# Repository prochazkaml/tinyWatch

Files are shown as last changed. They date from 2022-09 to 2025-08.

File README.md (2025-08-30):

# tinyWatch

A simple ATtiny3224-based wristwatch with an OLED display, a couple of buttons and a CR2032 battery.

tinywatch

To build your very own tinyWatch, you'll need to source the components, get a PCB made (or make it yourself, if you're brave enough), get the plastic parts 3D printed (or, again, print it yourself if you've already got a printer) and find a compatible 18 mm watch band + push pin (or edit the .scad files if you've got some other one).

## Plastic parts

The plastic parts of the tinyWatch are expected to be 3D printed (tested FDM, but SLA should work as well). They consist of:

- the back piece where the battery and PCB will be fit
- the front piece which will hold the OLED panel as well as the buttons in place, it also contains a pair of holes at each end for fitting a watch band push pin
- OLED support piece which will make the panel not fall inside of the watch
- 3x button caps

You can find these in the [hw/3D](https://github.com/prochazkaml/tinyWatch/tree/master/hw/3D) directory in .stl format with the .scad source files are available as well.

These parts are held together with an **M3 nut and M3x6 screw**.

## PCB & Hardware

The circuit diagram as well as the PCB were designed in KiCad, the project files are available in the [hw/kicad](https://github.com/prochazkaml/tinyWatch/tree/master/hw/kicad) directory. Many prototype PCB manufacturers support uploading raw KiCad files directly without the need to generate Gerber files. Recommended PCB thickness is 1.6 mm.

Of course, you will then need to populate the manufactured PCB with components. The bill of materials is available [here](https://github.com/prochazkaml/tinyWatch/blob/master/hw/kicad/tinywatch.csv) in CSV format. In summary, you'll need:

|Component|Package|Qty|DigiKey Part Number|
|-|-|-|-|
|4.7 μF capacitor|0603|1|1276-1044-1-ND|
|1 μF capacitor|0603|5|1276-1946-1-ND|
|2.2 μF capacitor|0603|1|1276-1040-1-ND|
|10 μF capacitor|0603|1|1276-1119-1-ND|
|1N4148W diode|SOD-123|1|311-4.70KHRTR-ND|
|4-pin straight female header|4x2.54 pitch|1|S7037-ND|
|SSD1306 128x64 0.96" OLED panel|30 pin flat ribbon, 0.7 mm pitch|1|3190-DLC0096DNOG-W-5-ND (but you can probably get it much cheaper [elsewhere](https://www.aliexpress.com/item/1005006114087000.html))|
|910k resistor|0603|1|13-AC0603FR-07910KLTR-ND|
|4.7k resistor|0603|1|311-4.70KHRTR-ND|
|Push button|6.7x4.1 mm|3|CKN12330-1-ND|
|ATtiny3224|SOIC-14|1|150-ATTINY3224-SSURCT-ND|
|32.768 kHz oscillator|3.2x2.5 mm|1|50-ECS-327TXO-30-CT-ND|

What is not included in the BOM is a **CR2032** battery, with specially shaped nickel strips welded to its terminals.
The assembly instructions below go into more detail on how to prepare and connect the battery correctly.

A cheap and perfectly usable watch band is available for example from [here](https://www.aliexpress.com/item/1005002369169370.html), just remember to select the 18 mm option. I personally opted for the "ML-Black" variant, it works just fine; it even comes with the required push pins embedded into the straps themselves.

## Assembly instructions

The hardware assembly instructions are available in [a separate document](ASSEMBLY.md).

Please note that the document already assumes that you have already assembled the required components onto the tinyWatch mainboard (excluding the battery).

## Firmware building instructions

The tinyWatch's firmware is written in Rust, so you'll need the Rust toolchain to be installed.

Bulding the firmware is as easy as running the following command:

```bash
cargo build --release
```

**NOTE**: This firmware is currently only compatible with revision 2 hardware with the new ATtiny3224 microcontroller. The old revision 1 hardware is only supported by the [old C-based firmware](https://github.com/prochazkaml/tinyWatch/tree/2073f80b21bf5213d320747aeb9541f89d2ae41b).

If you have a [serialupdi](https://github.com/SpenceKonde/AVR-Guidance/blob/master/UPDI/jtag2updi.md) programmer attached to the PC as well as the watch and want to upload the firmware to the watch, run the following:

```bash
avrdude -p attiny3224 -c serialupdi -P /dev/ttyUSB0 -v -U flash:w:target/avr-none/release/tinywatch.elf
```

## Power consumption

The watch consumes roughly **4.4 mA** while the screen is on, and about **3.4 μA** while the screen is off.

If you look at your watch for a total of 5 minutes each day, that would result in about **447 μAh** of power consumption **per day**. With this usage, the 220 mAh battery in the watch should last **more than a year**.

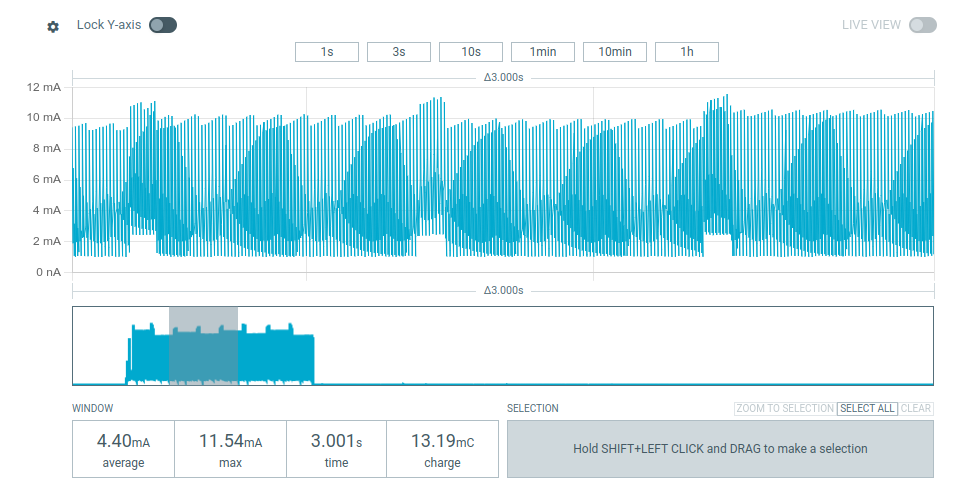
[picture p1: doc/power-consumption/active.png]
active_power_consumption


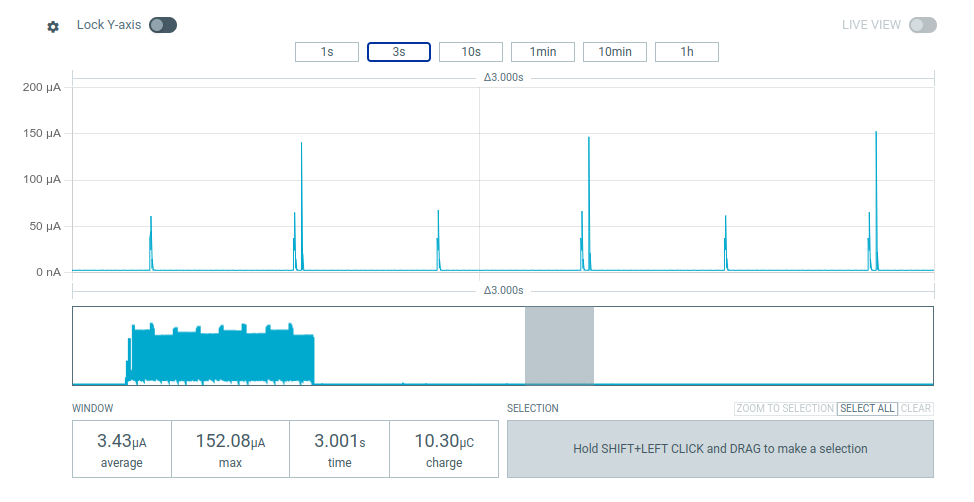
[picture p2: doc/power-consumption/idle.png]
idle_power_consumption


These measurements were taken using Nordic's [Power Profiler Kit 2](https://www.nordicsemi.com/Products/Development-hardware/Power-Profiler-Kit-2). The [raw capture file](doc/tinywatch_power_consumption.ppk2) can be viewed in the Power Profiler applet of the free and open source [nRF Connect for Desktop](https://www.nordicsemi.com/Products/Development-tools/nRF-Connect-for-Desktop) software.

## Setup

After flashing the firmware, you will want to set up the clock.
To do that, press the **left and right button** at simultaneously.
Then, using the **left** and **right** button, you will set the value on-screen and then press the **middle** button to confirm your selection and move onto the next value or finish the clock setup if you're done.
You will be asked at the end whether the entered values are correct.

## Oscillator calibration

> [!NOTE]  
> Revision 2 hardware uses a high quality temperature-compensated crystal oscillator with at most ±5 ppm of error, resulting in less than 0.5 seconds of drift per day.
> With this hardware, this option should be left alone.

If you experience severe drifts with the watch (more than 1 second per day), it is possible to trim the oscillator to a more precise value.

To remedy this issue, press the **left and middle button** together to enter the clock calibration menu.
There, you will be presented by a 16-bit hex value (the default is 8000, corresponding to the 32.768 kHz of the main oscillator).
With the **left** and **right** button, you can move the cursor.

To edit a value of a digit, press the **middle** button (the cursor will appear above the digit so that it is apparent what the buttons currently do)
and adjust the value using the **left** and **right** button.

To confirm your choice, press the **middle** button again to go back to cursor mode. Choose `Done` and press the **middle** button to exit.

## General usage

Once your watch is set up with the correct time, it is now ready to serve your everyday needs of checking the time.
Simply push any of its buttons and it will light up for a few seconds to tell you the time, before turning off again to conserve power.

---

That's it! Enjoy your watch. More features coming soon ;)

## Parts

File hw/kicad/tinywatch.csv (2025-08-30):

Reference | Value | Footprint | Qty
C1 | 4u7 | Capacitor_SMD:C_0603_1608Metric_Pad1.08x0.95mm_HandSolder | 1
C2,C3,C4,C5,C8 | 1u | Capacitor_SMD:C_0603_1608Metric_Pad1.08x0.95mm_HandSolder | 5
C6 | 2u2 | Capacitor_SMD:C_0603_1608Metric_Pad1.08x0.95mm_HandSolder | 1
C7 | 10u | Capacitor_SMD:C_0603_1608Metric_Pad1.08x0.95mm_HandSolder | 1
D1 | 1N4148W | Diode_SMD:D_SOD-123 | 1
J1 | Conn_01x04 | Connector_PinSocket_2.54mm:PinSocket_1x04_P2.54mm_Horizontal | 1
J2 | Conn_01x30 | Display:OLED-128O064D | 1
R4 | 910k | Resistor_SMD:R_0603_1608Metric_Pad0.98x0.95mm_HandSolder | 1
R5 | 4k7 | Resistor_SMD:R_0603_1608Metric_Pad0.98x0.95mm_HandSolder | 1
SW1,SW2,SW3 | SW_Push | Button_Switch_SMD:SW_DIP_SPSTx01_Slide_6.7x4.1mm_W6.73mm_P2.54mm_LowProfile_JPin | 3
U1 | ATtiny3224-SS | Package_SO:SOIC-14_3.9x8.7mm_P1.27mm | 1
Y2 | ECS-327TXO-30 | Oscillator:Oscillator_SMD_EuroQuartz_XO32-4Pin_3.2x2.5mm | 1

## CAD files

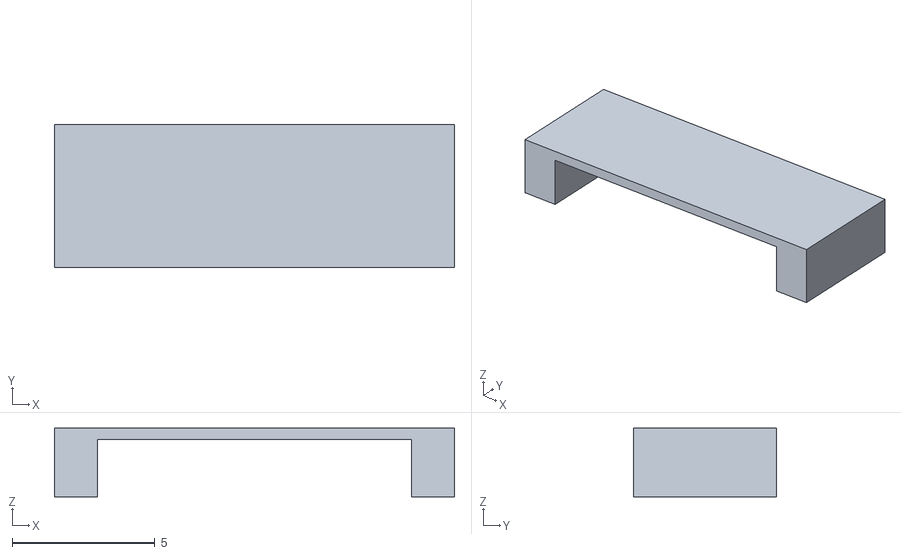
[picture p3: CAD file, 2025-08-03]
hw/3D/oledsupport.stl
14.0 x 5.00 x 2.40

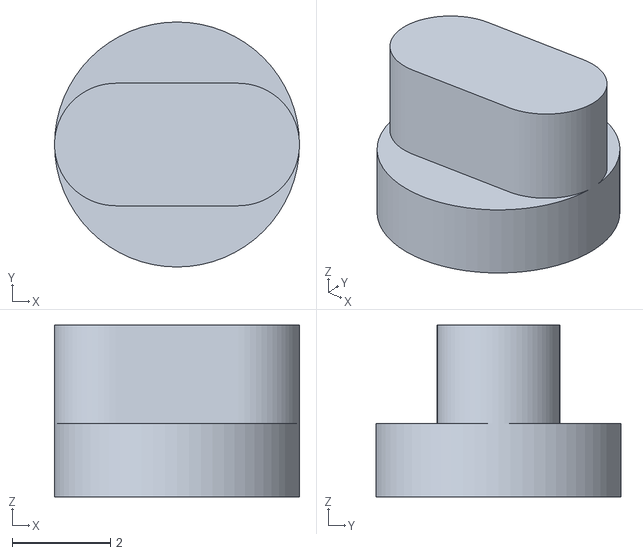
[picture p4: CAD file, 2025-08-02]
hw/3D/buttons.stl
5.00 x 5.00 x 3.50

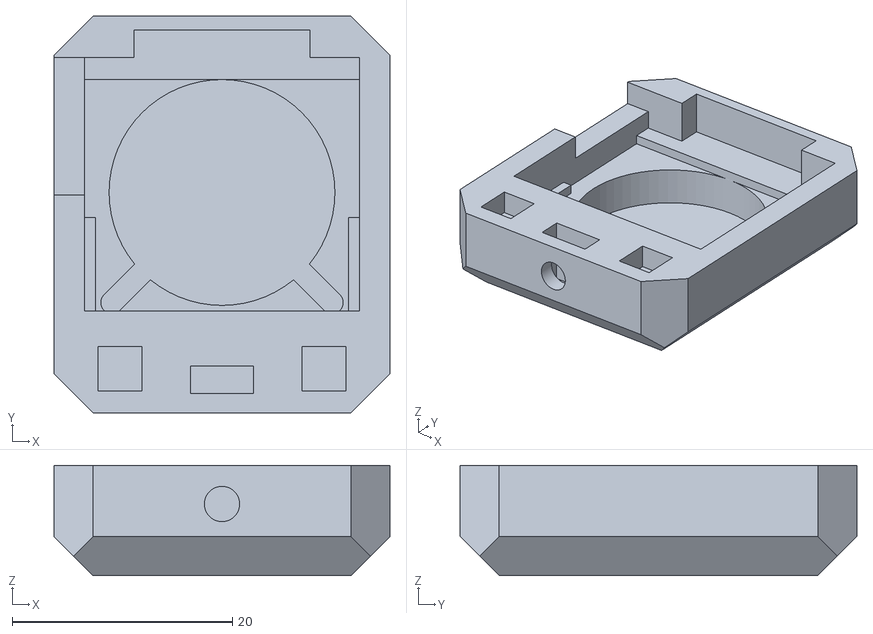
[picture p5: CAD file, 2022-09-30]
hw/3D/watch.stl
30.5 x 36.0 x 10.0

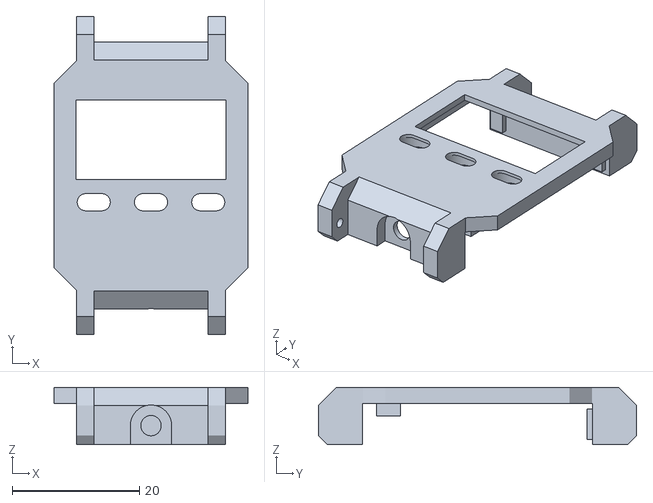
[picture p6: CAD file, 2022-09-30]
hw/3D/watchstrap.stl
30.5 x 50.0 x 8.96

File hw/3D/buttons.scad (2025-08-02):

include <common.scad>

module buttonhole() {
	cylinder(d = 5, h = lcd_d);
	
	hull() {
		translate([-1.25, 0]) cylinder(d = 2.5, h = 3.5);
		translate([1.25, 0]) cylinder(d = 2.5, h = 3.5);
	}
}

translate([0, 0]) buttonhole();
// translate([-9, 0]) buttonhole();
// translate([9, 0]) buttonhole();

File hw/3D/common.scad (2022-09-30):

$fn = 64;

body_w = 30.5;
body_h = 36;
body_d = 10;

emboss = 5;

tolerances = .1;
dtolerances = tolerances * 2;

lcd_top_offset = 2.5;

lcd_w = 24.8;
lcd_h = 16.7;
lcd_d = 1.5;

lcd_border = .6;
lcd_chin = 3;

strappole_w = 21;
strappole_d = 1.5;

top_d = lcd_d + 1;

module nuthole(w) {
	translate([-5.75/2, -2.5/2, -6.5/2]) cube([5.75, 2.5, 999]);
	
	rotate([90, 0, 0]) cylinder(h = w, d = 3.2, center = true);	
}

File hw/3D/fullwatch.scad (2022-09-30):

translate([0, 0, 10.1]) import("watchstrap.stl");
import("watch.stl");

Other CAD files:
hw/3D/oledsupport.scad
hw/3D/watch.scad
hw/3D/watchstrap.scad

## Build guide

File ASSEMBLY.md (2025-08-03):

# Hardware assembly instructions

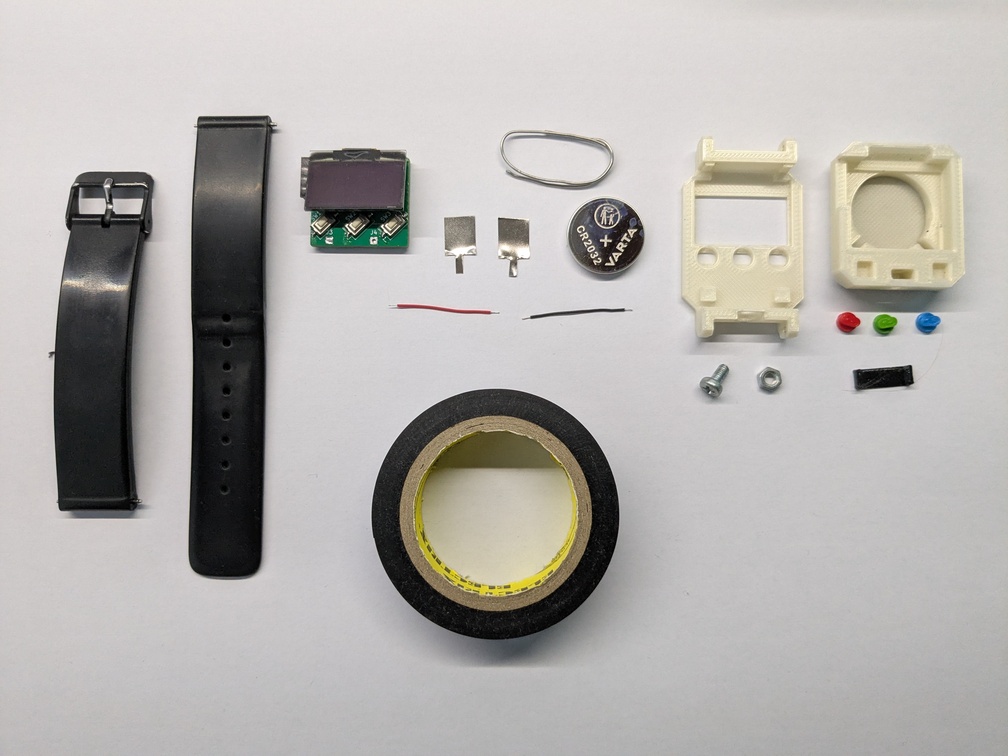
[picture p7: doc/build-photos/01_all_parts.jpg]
all_parts


To start, you will need:

- An assembled tinyWatch mainboard.
- All 3D printed pieces (body, front, buttons (3 pcs.), OLED support piece).
- A new CR2032 battery.
- An M3 hex nut and an M3x6 screw.
- A 18 mm wide watch strap.
- Two pieces of nickel strip cut to a weird "T"-like shape (so that the middle bit is no more than 2 mm wide and about 5 mm deep).
- Two short pieces of thin wire (about 20 mm in length, I use cheap 30 AWG "wire wrapping" wire).
- Some solder.
- Some electrical tape and a small piece of double-sided tape (not in the picture).

Required tools:

- A soldering iron. You probably already have one if you were able to assemble the mainboard.
- A spot welder. I use [this cheap battery-powered one](https://www.aliexpress.com/item/1005006226735630.html), it does the job just fine.
- Some precise pliers or a sharp knife to create the nickel strips shown above.
- A screwdriver.
- (_optional_) A pair of bent tip tweezers to make placing things easier

> [!TIP] 
> If you have access to more than one color of 3D printable material,
> do not be afraid to experiment to make your watch truly unique
> (such as with the buttons colors).

## Preparing the battery

First, solder the short pieces of wire onto the middle "base" of the nickel strips.

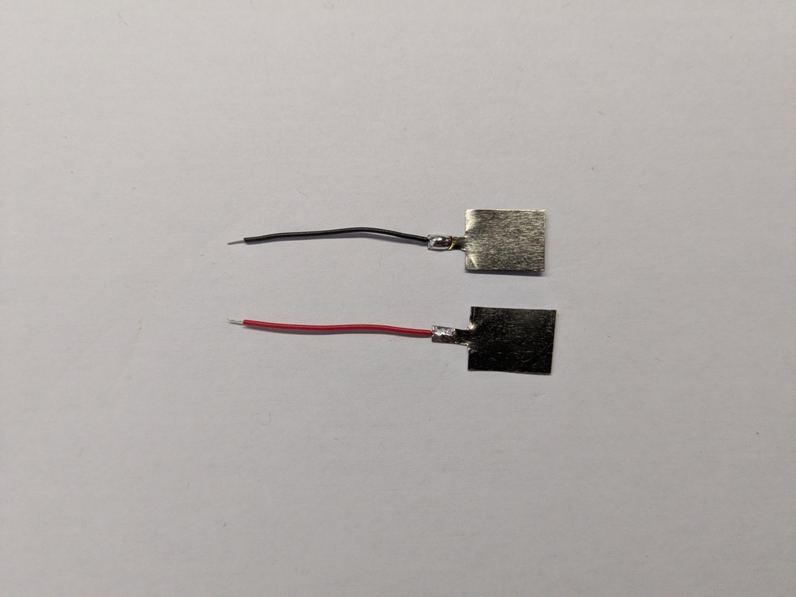
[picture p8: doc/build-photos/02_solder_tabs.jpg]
solder_tabs


Start by spot welding the nickel strip to the positive terminal of the battery.

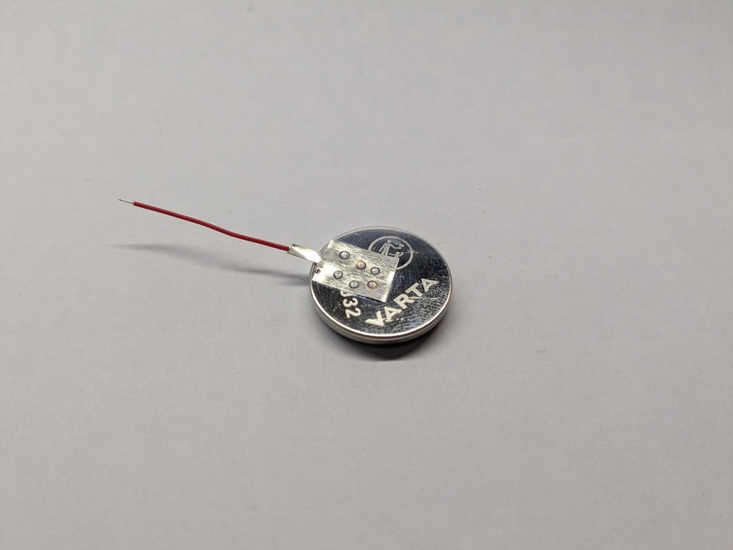
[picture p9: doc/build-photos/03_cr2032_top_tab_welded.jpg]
cr2032_top_tab_welded

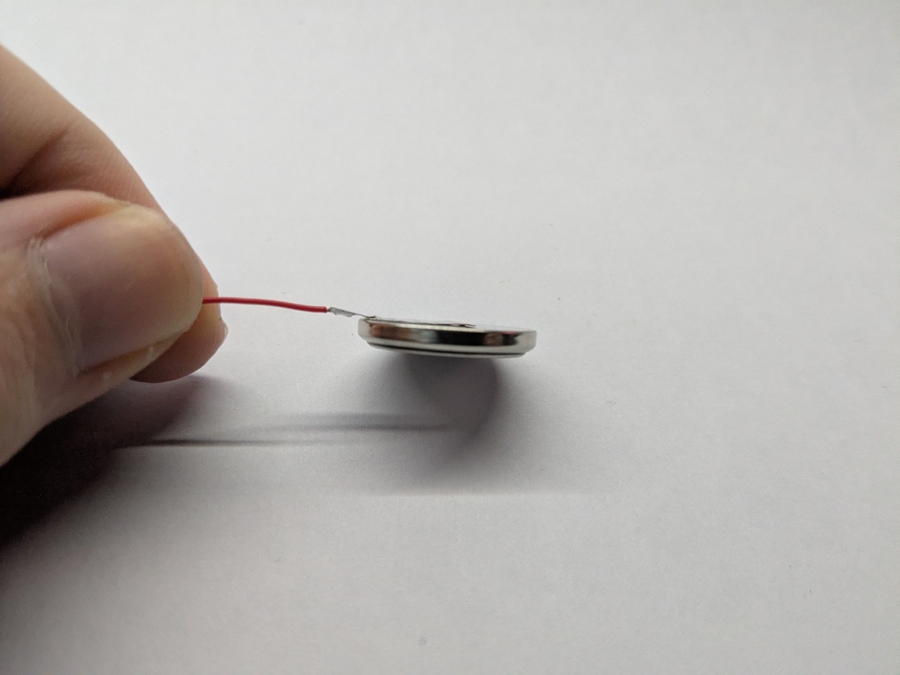
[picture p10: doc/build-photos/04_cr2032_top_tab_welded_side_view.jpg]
cr2032_top_tab_welded_side_view


Before spot welding to the bottom terminal, place a piece of electrical tape around the seam of the positive and negative terminal of the battery to prevent accidental short circuits. Place this tape 90° counter-clockwise from where the positive wire is pointing.

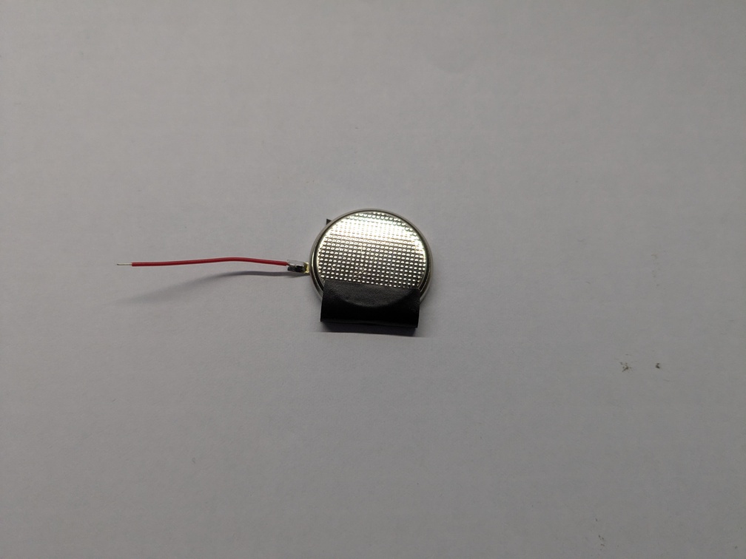
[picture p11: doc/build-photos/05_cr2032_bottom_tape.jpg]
cr2032_bottom_tape

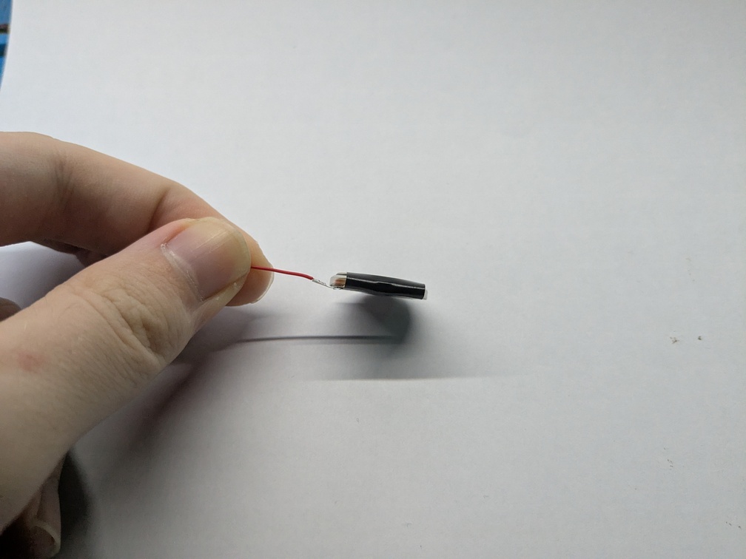
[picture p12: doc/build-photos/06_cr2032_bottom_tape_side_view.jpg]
cr2032_bottom_tape_side_view

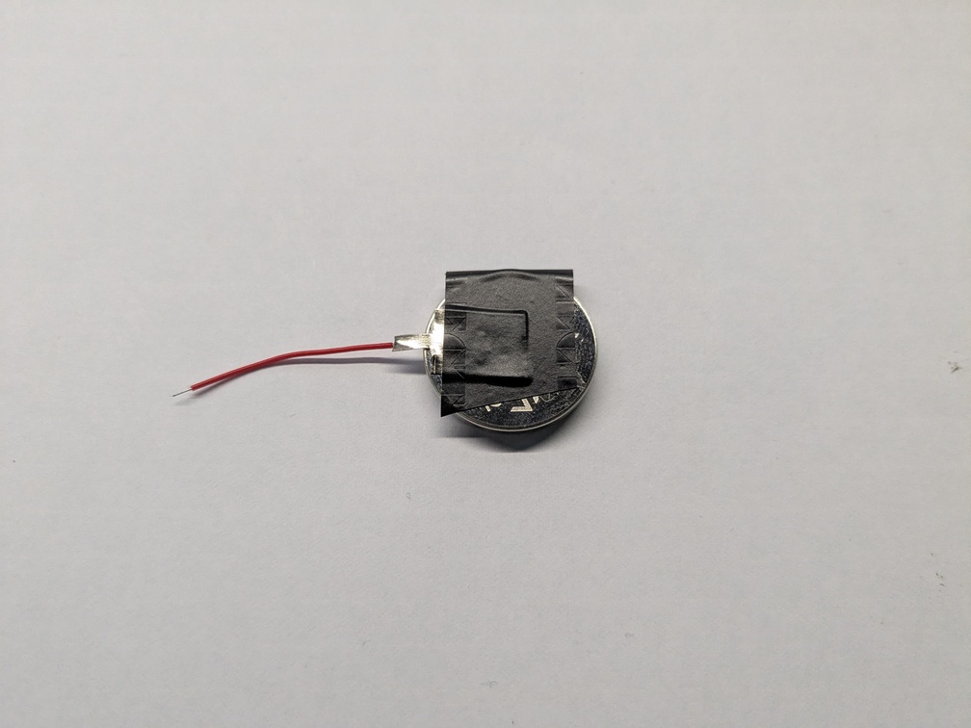
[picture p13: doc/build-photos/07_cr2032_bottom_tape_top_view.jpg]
cr2032_bottom_tape_top_view


Then, weld the second nickel strip to the negative terminal of the battery, over the tape.

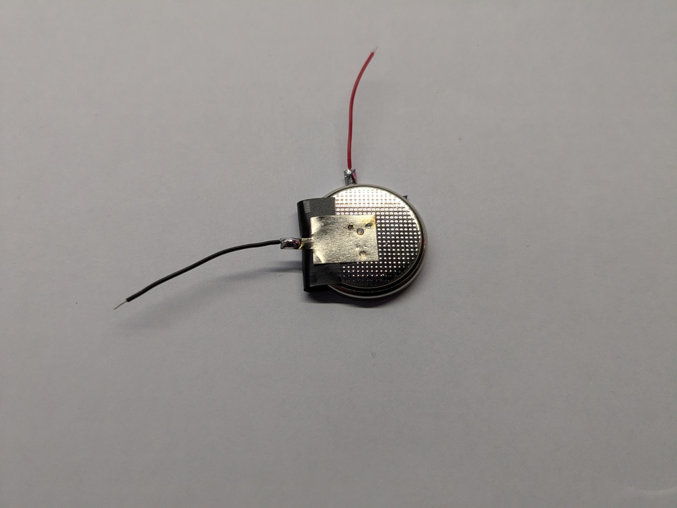
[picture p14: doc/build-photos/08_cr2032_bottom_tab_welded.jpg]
cr2032_bottom_tab_welded


You should end up with a battery that has two wires coming out of it, offset by a 90° angle.

> [!IMPORTANT]
> Make sure that when looking at the battery with its positive terminal on the top,
> the positive wire should be 90° counter-clockwise from the negative wire.

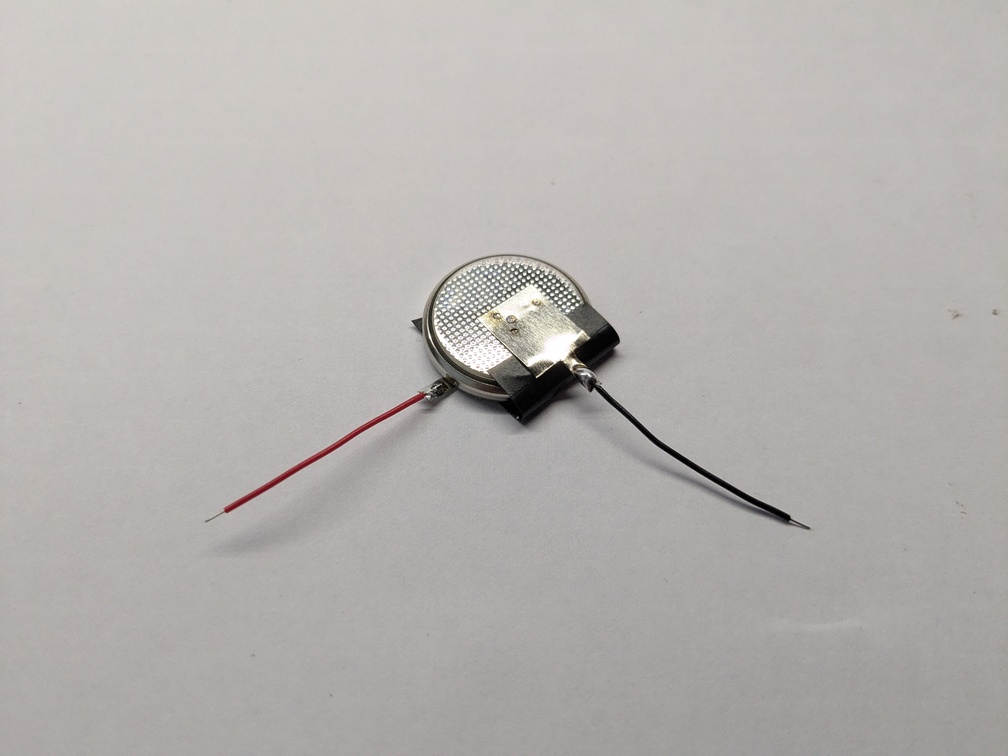
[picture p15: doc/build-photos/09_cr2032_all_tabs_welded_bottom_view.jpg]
cr2032_all_tabs_welded_bottom_view

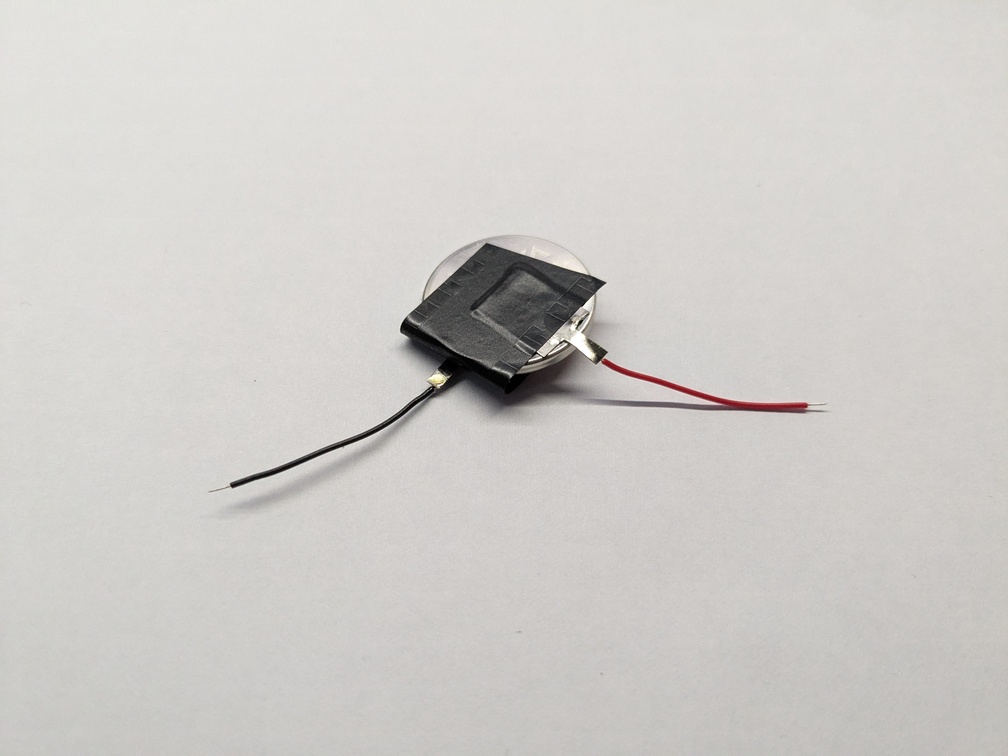
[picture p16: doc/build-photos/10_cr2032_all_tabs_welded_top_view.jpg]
cr2032_all_tabs_welded_top_view


## Installing the battery and mainboard

Bend the wires coming out of the battery upward and insert it into the main body.

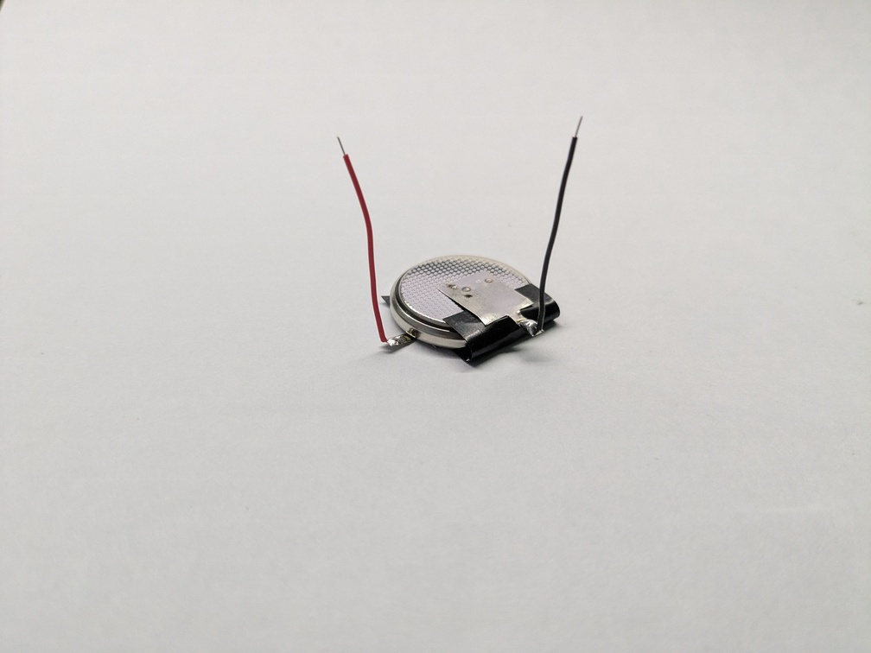
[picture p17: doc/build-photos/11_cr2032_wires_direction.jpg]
cr2032_wires_direction

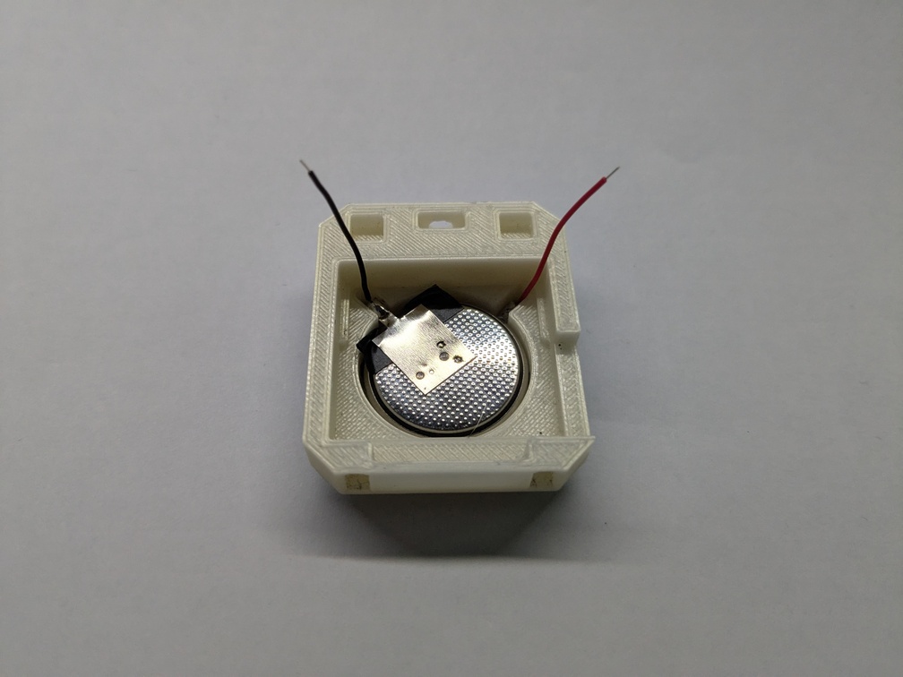
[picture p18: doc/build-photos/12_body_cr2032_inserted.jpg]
body_cr2032_inserted


Place some electrical tape over the newly inserted battery, so that it does not accidentaly short out with the mainboard during daily use.

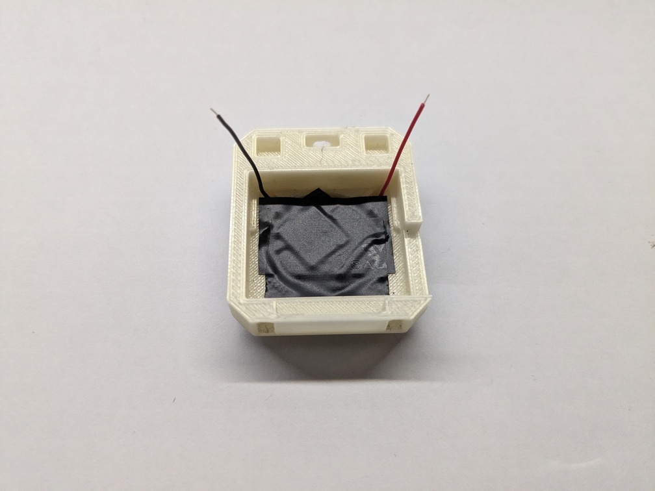
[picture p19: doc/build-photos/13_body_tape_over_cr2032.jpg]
body_tape_over_cr2032

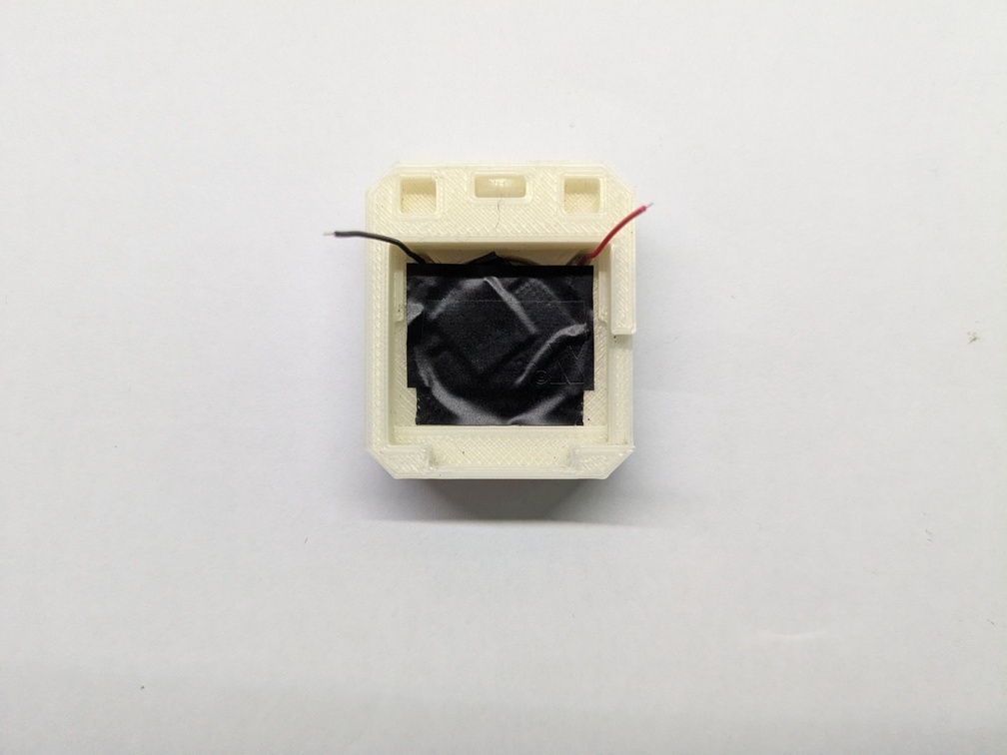
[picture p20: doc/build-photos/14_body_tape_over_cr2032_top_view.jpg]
body_tape_over_cr2032_top_view


Connect the battery to the mainboard.

> [!IMPORTANT]
> Make sure that the polarity is correct -
> the negative wire connects to the "-" terminal on the mainboard,
> while the positive wire connects to the "+" terminal.

> [!TIP]
> If your mainboard is not yet programmed, it will consume a few mA of current,
> pointlessly draining the battery. It is highly recommended to connect a programmer
> to the mainboard **now** and flash the firmware, which will also verify
> that the watch is working correctly.

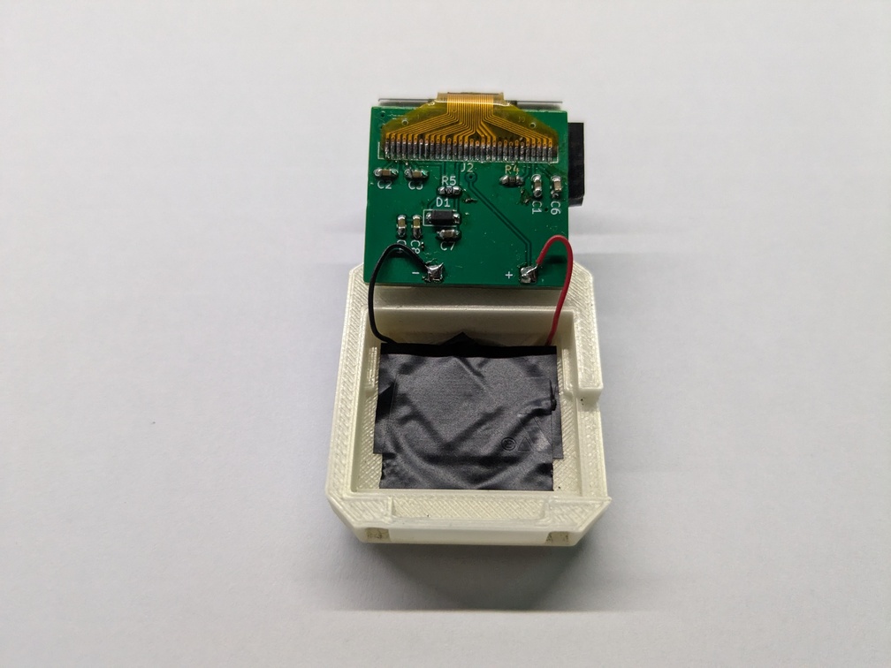
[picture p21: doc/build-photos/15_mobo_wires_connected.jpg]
mobo_wires_connected


Push the mainboard firmly into the body. The buttons as well as the debug/communication connector should be flush with the top of the body.

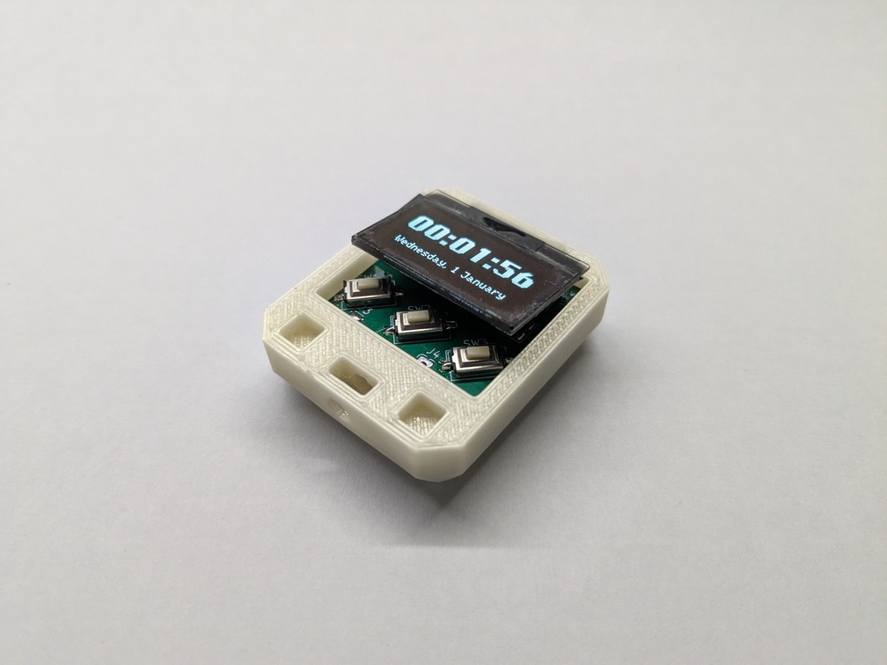
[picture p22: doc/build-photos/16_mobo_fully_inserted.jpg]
mobo_fully_inserted

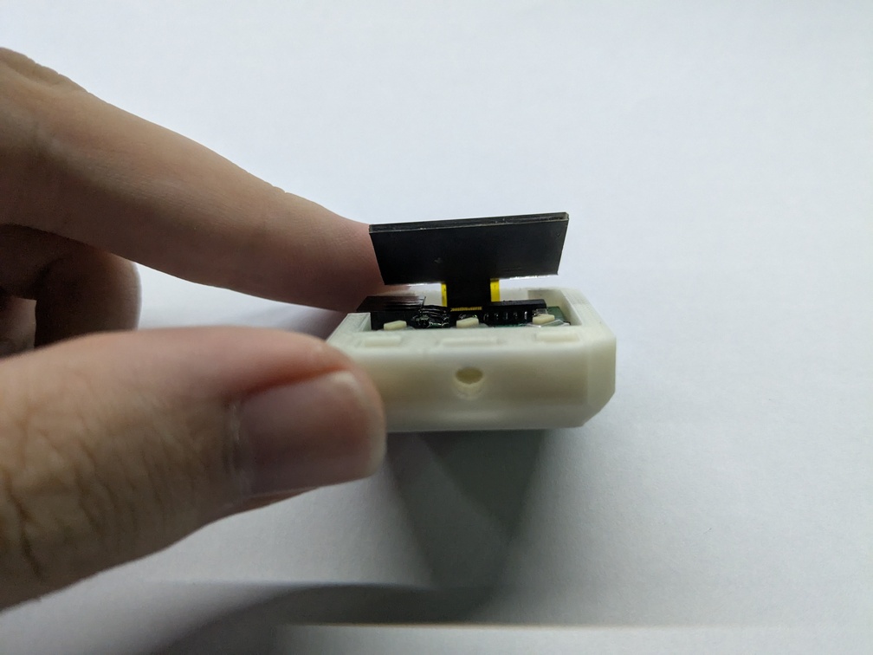
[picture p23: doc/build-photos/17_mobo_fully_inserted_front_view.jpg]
mobo_fully_inserted_front_view

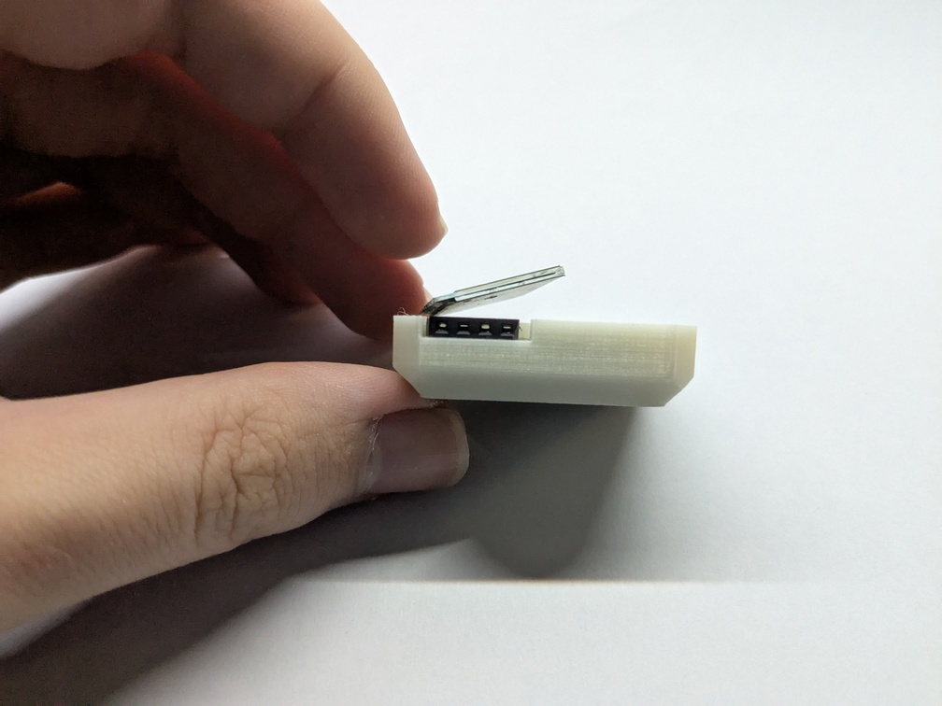
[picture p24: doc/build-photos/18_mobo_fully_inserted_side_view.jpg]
mobo_fully_inserted_side_view


Place the OLED support piece on top of the main microcontroller with a piece of double-sided tape on it.
If you then push the OLED panel down, the support piece should stick to it.

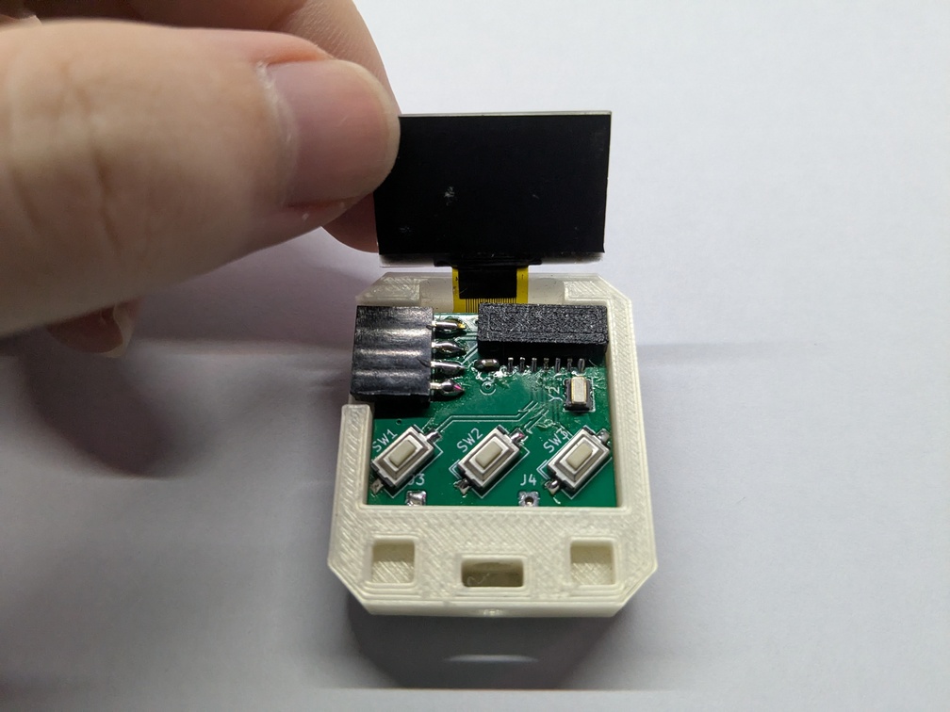
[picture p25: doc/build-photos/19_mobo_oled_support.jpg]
mobo_oled_support

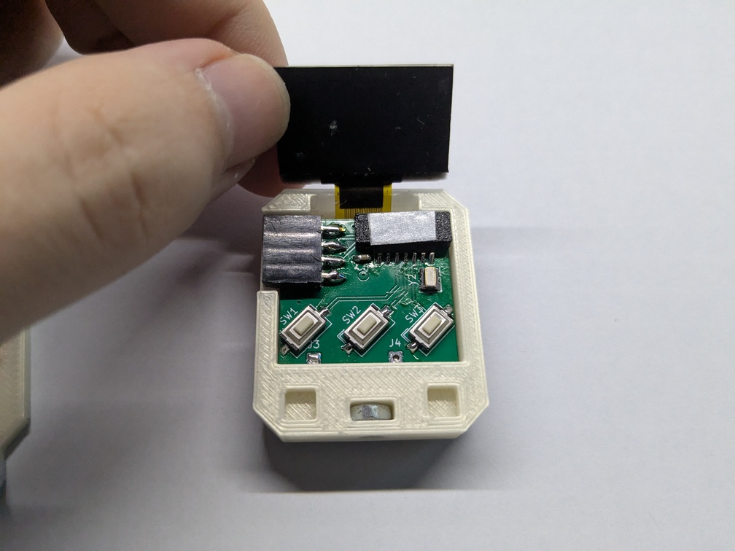
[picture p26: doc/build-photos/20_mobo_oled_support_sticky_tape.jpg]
mobo_oled_support_sticky_tape

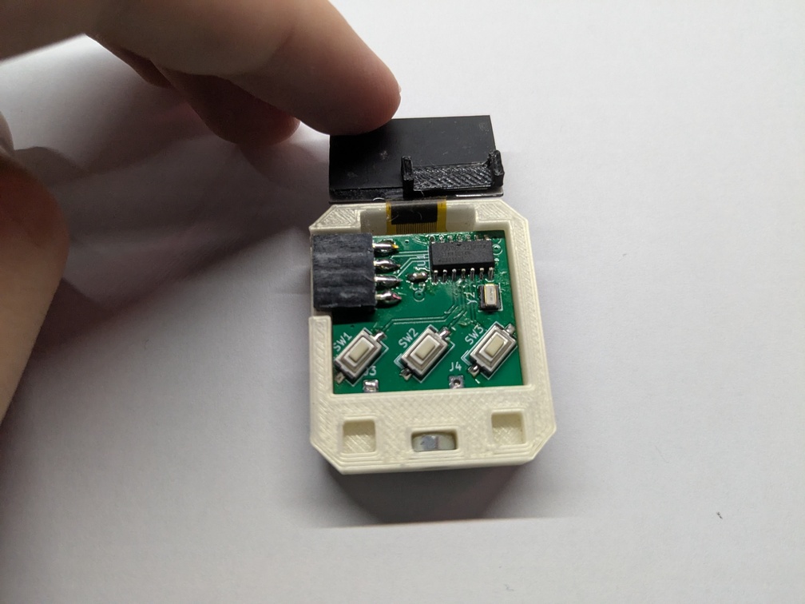
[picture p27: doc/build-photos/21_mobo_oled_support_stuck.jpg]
mobo_oled_support_stuck


## Final assembly

Insert the M3 hex nut into the hole in the body.

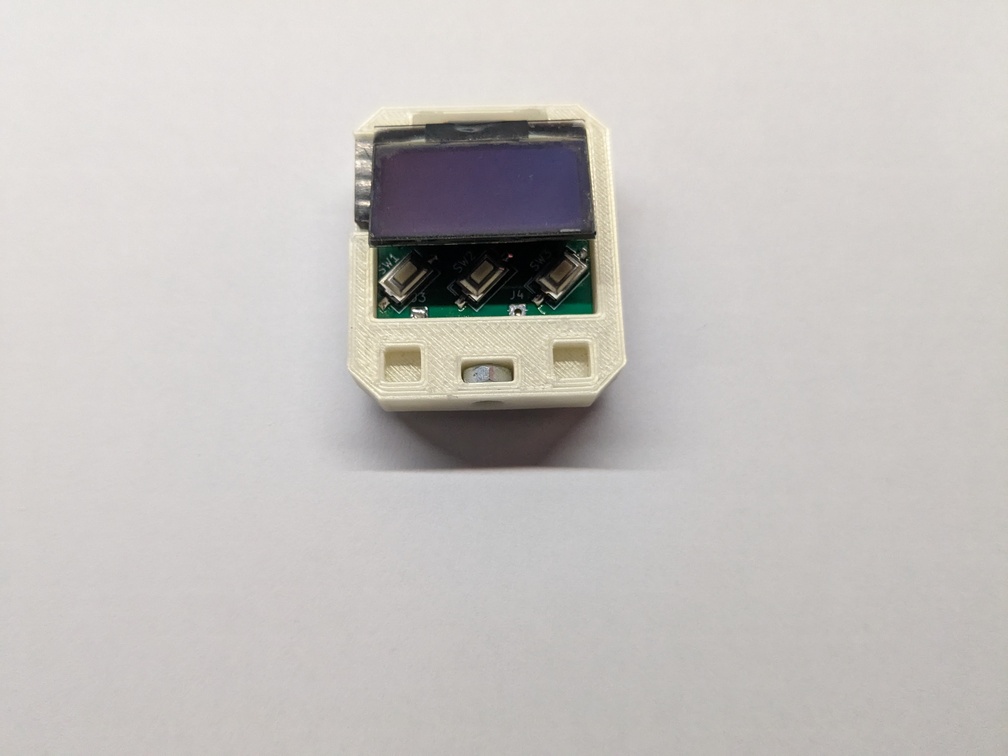
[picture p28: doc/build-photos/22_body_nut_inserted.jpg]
body_nut_inserted


> [!TIP]
> To verify that the nut is placed correctly, you can try temporarily screwing in the screw into the body.
> It should screw in smoothly.
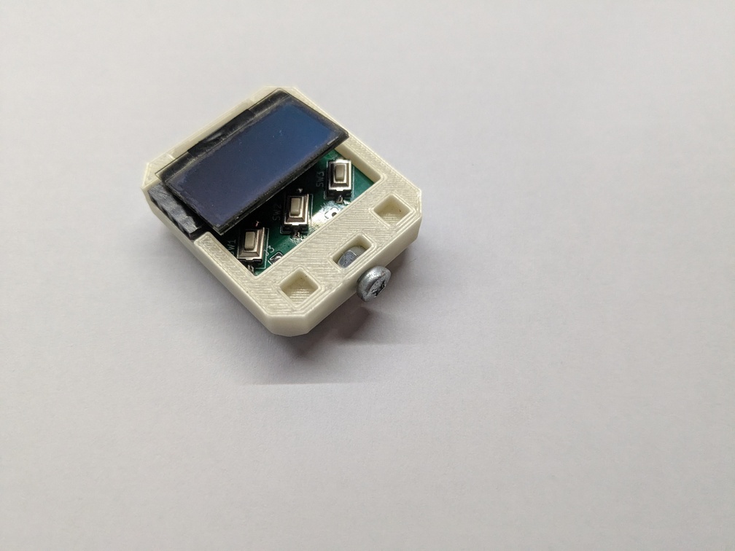
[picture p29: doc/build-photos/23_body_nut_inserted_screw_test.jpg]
body_nut_inserted_screw_test
> 

Place the buttons into the front piece.

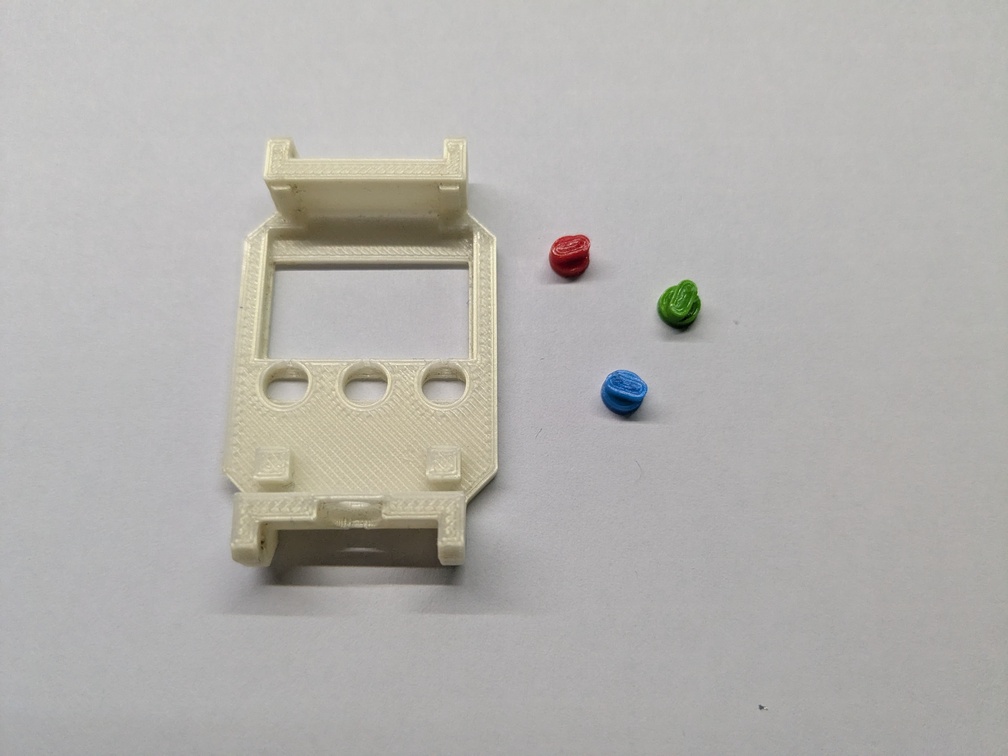
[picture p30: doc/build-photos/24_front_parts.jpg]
front_parts

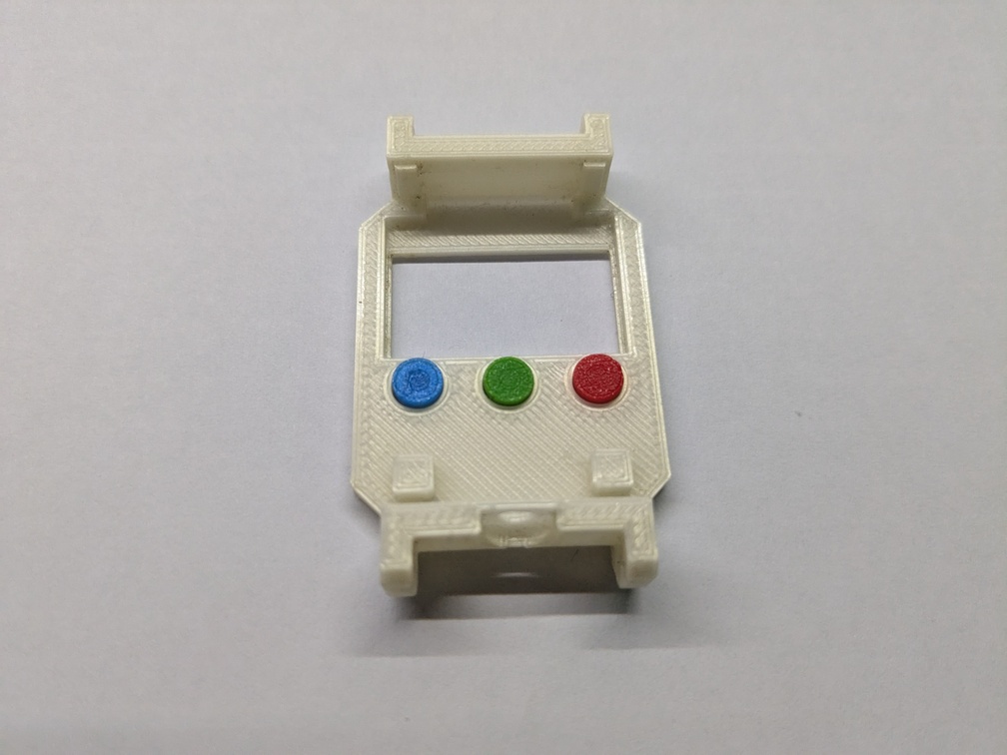
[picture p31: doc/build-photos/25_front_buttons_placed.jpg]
front_buttons_placed


Now, for the tricky part - closing the entire unit. The easiest way to do this is to hold the main body vertically with the front piece "hanging" from it. This way, neither the nut nor the buttons will fall out during final assembly.

Place the OLED panel into the front piece so that the bottom of the panel is seated in the bottom of the display hole in the front piece.

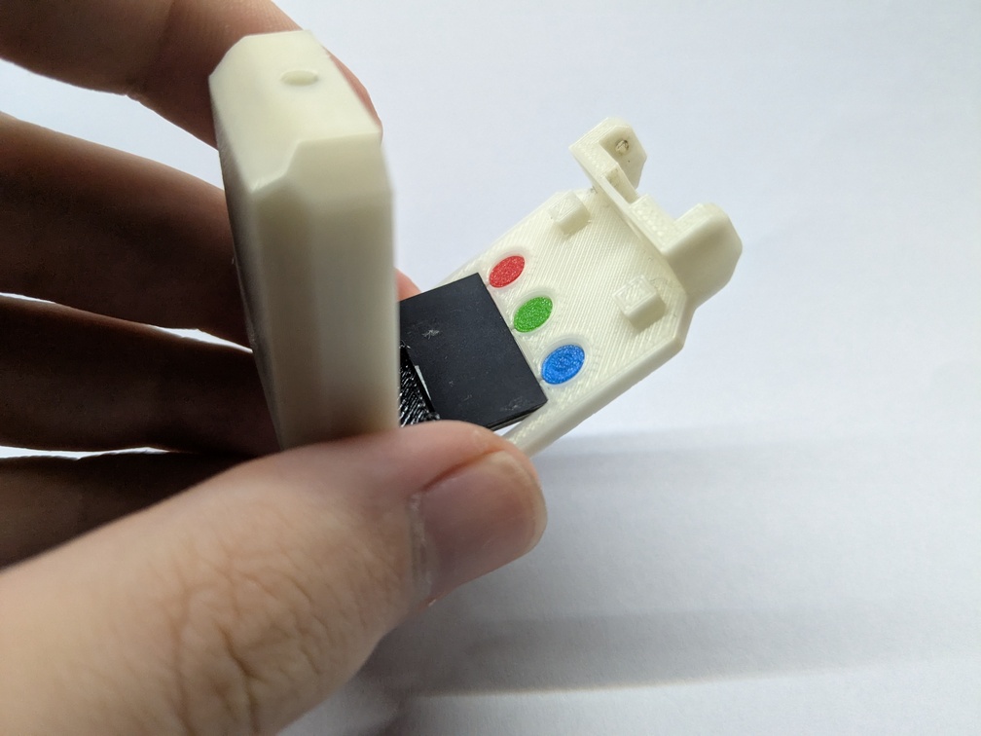
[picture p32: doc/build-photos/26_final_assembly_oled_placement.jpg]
final_assembly_oled_placement

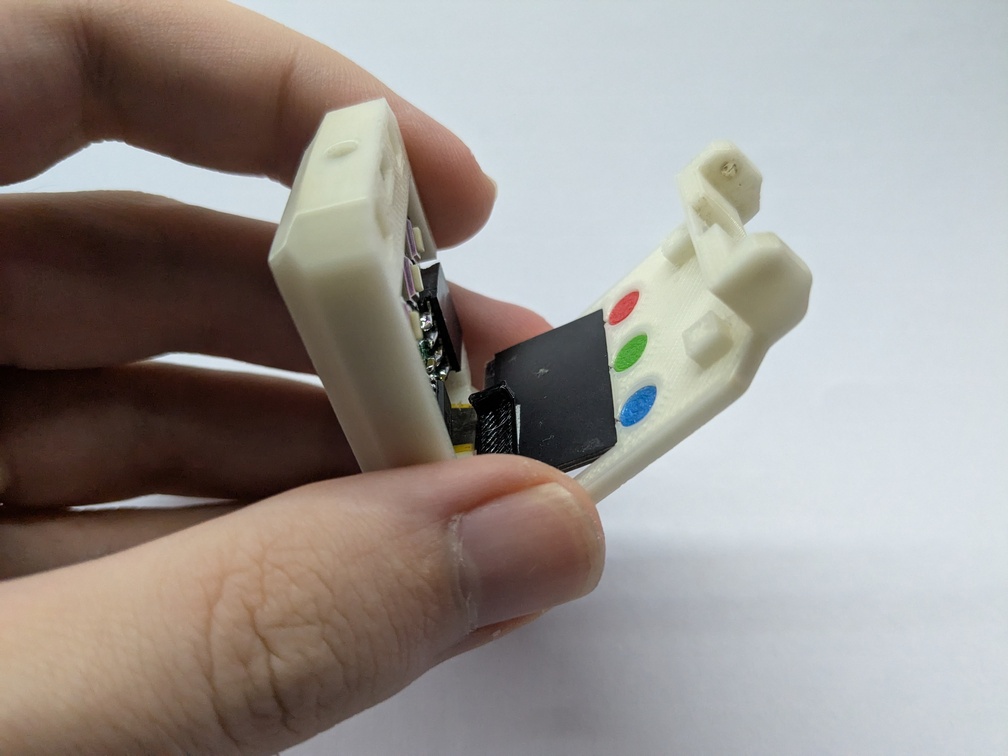
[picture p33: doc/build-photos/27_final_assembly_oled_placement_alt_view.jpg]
final_assembly_oled_placement_alt_view


Then, it should just close together without issues. Make sure that the front piece does not bulge, then screw it down into the main body.

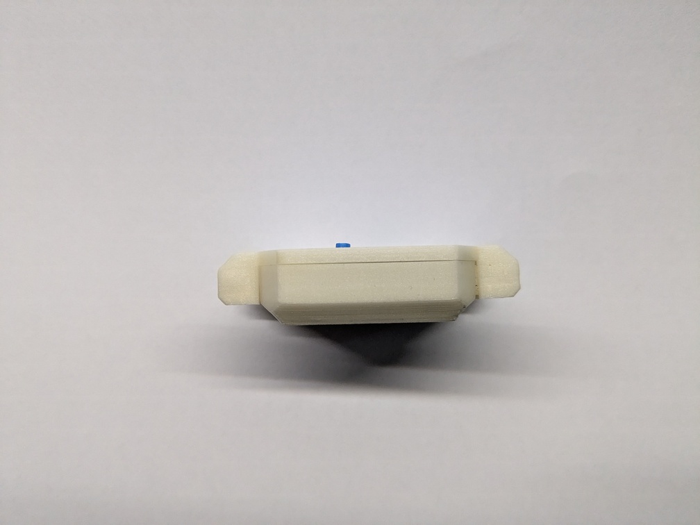
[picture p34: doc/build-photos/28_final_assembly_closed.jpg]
final_assembly_closed

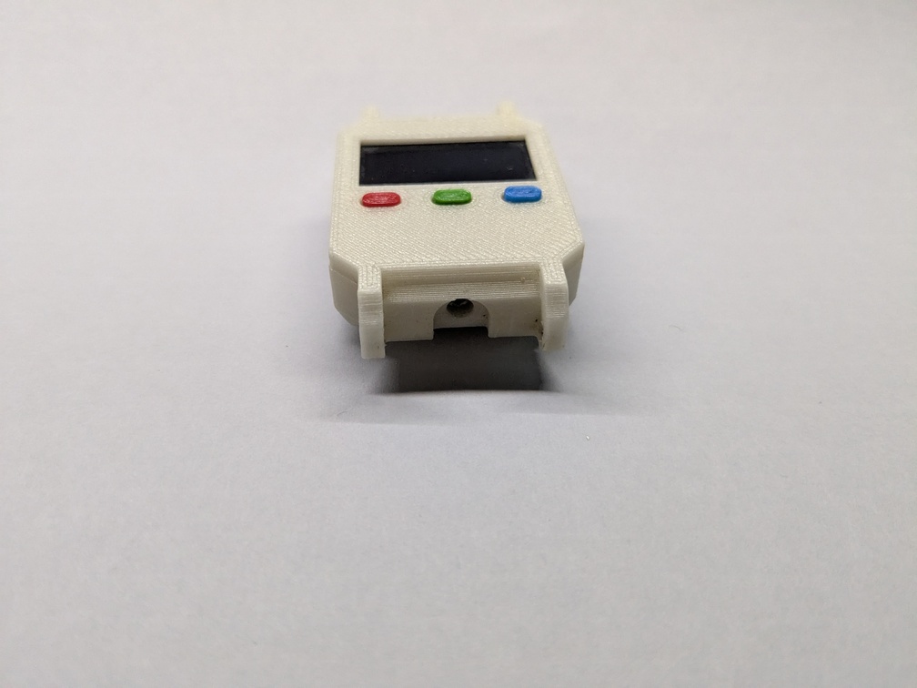
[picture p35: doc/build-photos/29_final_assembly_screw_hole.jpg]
final_assembly_screw_hole

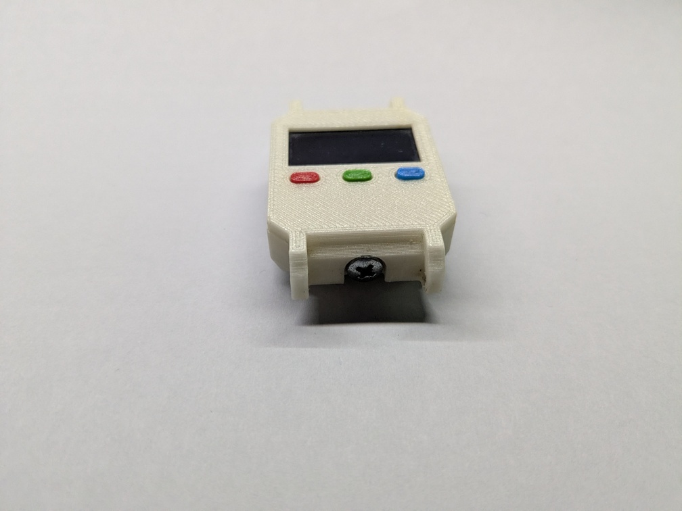
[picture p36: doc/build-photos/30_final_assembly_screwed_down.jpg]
final_assembly_screwed_down


## Strap attachment

Attaching the strap is as easy with any other watch - simply press one side of the strap's push pin into the watch, press the push pin and slide the whole strap into the watch so that the push pin locks the strap in place.

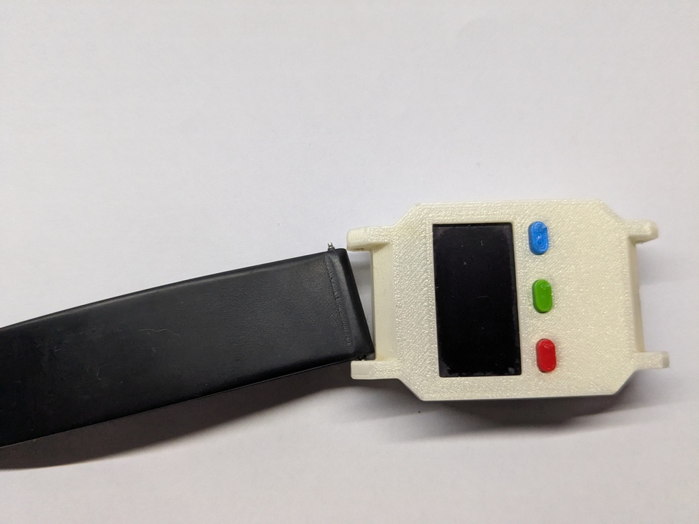
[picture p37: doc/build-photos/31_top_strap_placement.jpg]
top_strap_placement

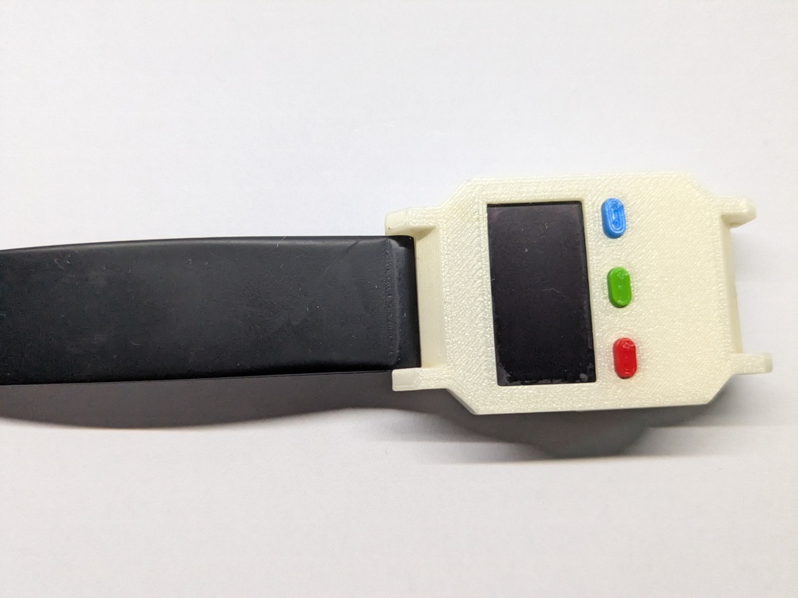
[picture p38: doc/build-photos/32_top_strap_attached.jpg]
top_strap_attached


Do the same with the bottom strap.

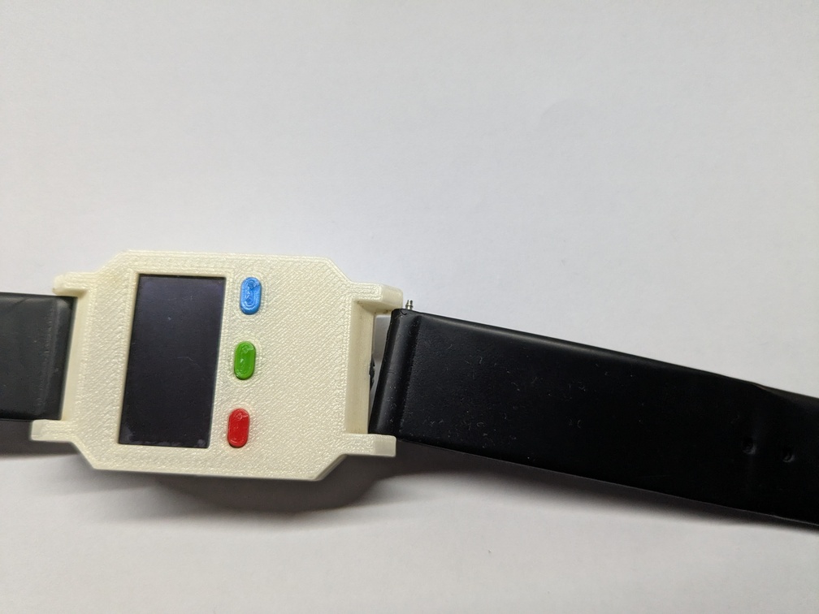
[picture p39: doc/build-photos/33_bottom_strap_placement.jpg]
bottom_strap_placement

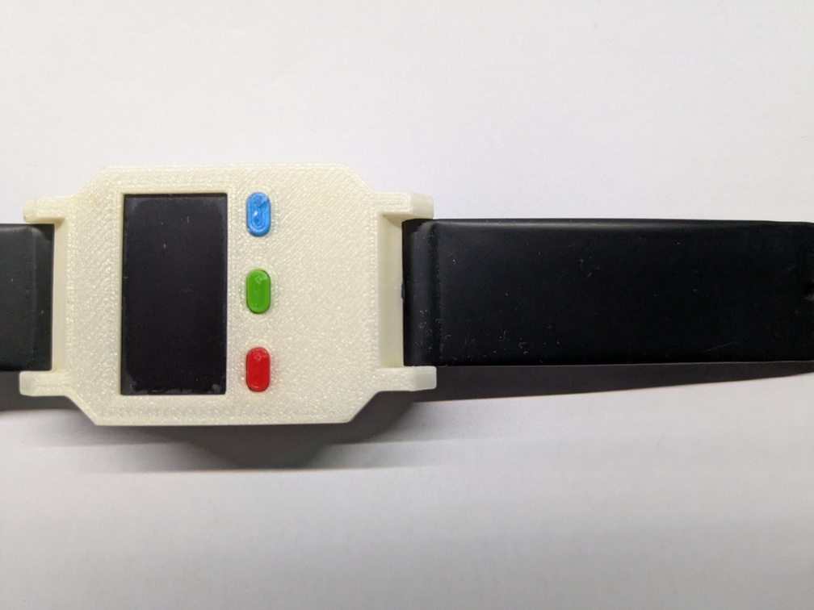
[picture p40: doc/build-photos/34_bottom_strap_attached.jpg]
bottom_strap_attached


## Finish

Congratulations, you should now have a fully functioning tinyWatch!

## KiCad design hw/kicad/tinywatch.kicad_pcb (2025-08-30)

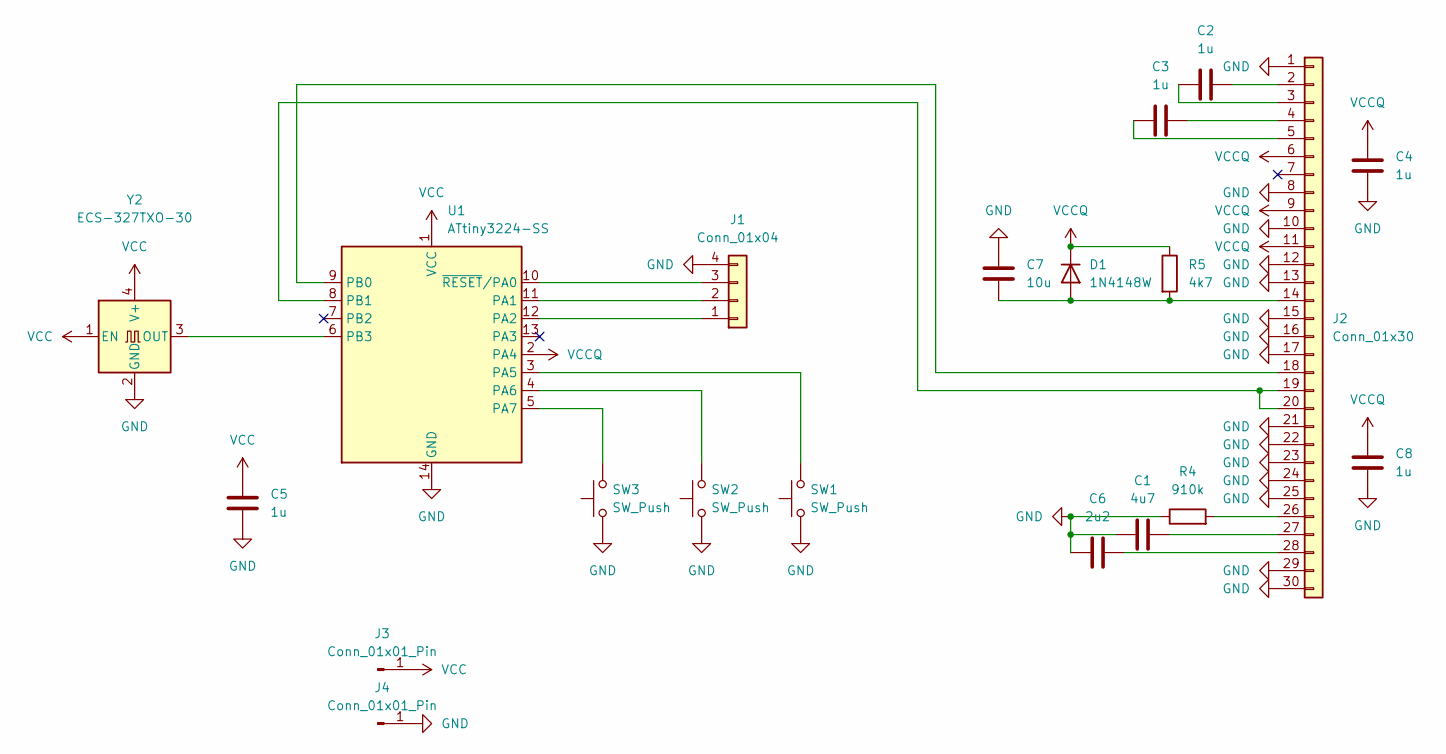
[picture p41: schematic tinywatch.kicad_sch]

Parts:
C1: 4u7; C_0603_1608Metric_Pad1.08x0.95mm_HandSolder
C2, C3, C4, C5, C8: 1u; C_0603_1608Metric_Pad1.08x0.95mm_HandSolder
C6: 2u2; C_0603_1608Metric_Pad1.08x0.95mm_HandSolder
C7: 10u; C_0603_1608Metric_Pad1.08x0.95mm_HandSolder
D1: 1N4148W; D_SOD-123
J1: Conn_01x04; PinSocket_1x04_P2.54mm_Horizontal
J2: Conn_01x30; OLED-128O064D
J3, J4: Conn_01x01_Pin; SolderWire-0.25sqmm_1x01_D0.65mm_OD1.7mm
R4: 910k; R_0603_1608Metric_Pad0.98x0.95mm_HandSolder
R5: 4k7; R_0603_1608Metric_Pad0.98x0.95mm_HandSolder
SW1, SW2, SW3: SW_Push; SW_DIP_SPSTx01_Slide_6.7x4.1mm_W6.73mm_P2.54mm_LowProfile_J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
U1: ATtiny3224-SS; SOIC-14_3.9x8.7mm_P1.27mm
Y2: ECS-327TXO-30; Oscillator_SMD_Abracon_ASE-4Pin_3.2x2.5mm

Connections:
GND: C1.1, C4.2, C5.2, C6.1, C7.1, C8.2, J1.4, J2.1, J2.8, J2.10, J2.12, J2.13, J2.15, J2.16, J2.17, J2.21, J2.22, J2.23, J2.24, J2.25, J2.29, J2.30, J4.1, R4.1, SW1.1, SW2.1, SW3.1, U1.14 (GND), Y2.2 (GND)
unnamed: C7.2, D1.2 (A), J2.14, R5.2
unnamed: J1.1, U1.12 (PA2)
unnamed: J1.2, U1.11 (PA1)
unnamed: J1.3, U1.10 (~RESET/PA0)
unnamed: C2.2, J2.2
unnamed: C2.1, J2.3
unnamed: C3.2, J2.4
unnamed: C3.1, J2.5
unnamed: J2.18, U1.9 (PB0)
unnamed: J2.19, J2.20, U1.8 (PB1)
unnamed: J2.26, R4.2
unnamed: C1.2, J2.27
unnamed: C6.2, J2.28
unnamed: SW1.2, U1.3 (PA5)
unnamed: SW2.2, U1.4 (PA6)
unnamed: SW3.2, U1.5 (PA7)
unnamed: U1.6 (PB3), Y2.3 (OUT)
VCC: C5.1, J3.1, U1.1 (VCC), Y2.1 (EN), Y2.4 (V+)
VCCQ: C4.1, C8.1, D1.1 (K), J2.6, J2.9, J2.11, R5.1, U1.2 (PA4)

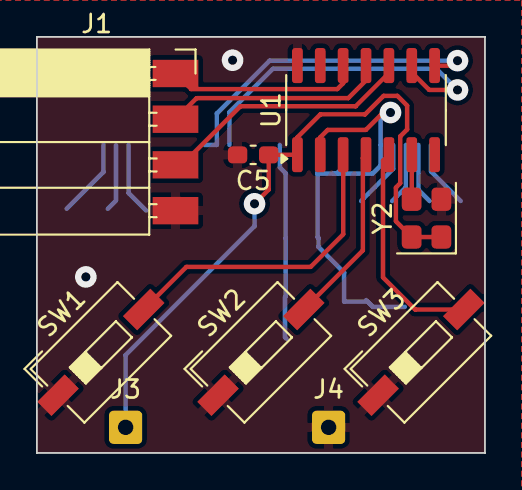
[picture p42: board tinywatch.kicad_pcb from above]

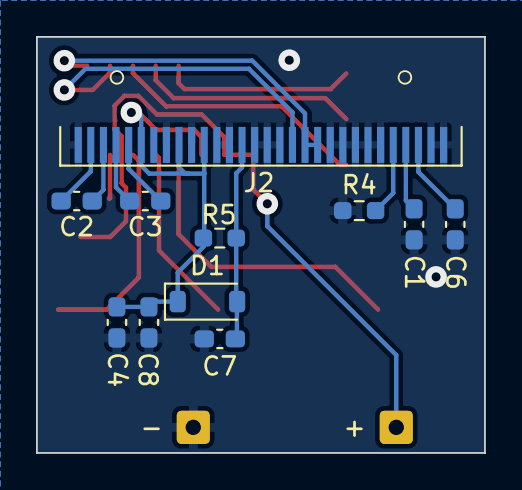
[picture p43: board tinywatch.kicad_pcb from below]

Board: 2 copper layers, 24.9 x 23.1 mm, 20 parts (11 on the bottom side), 20 nets.

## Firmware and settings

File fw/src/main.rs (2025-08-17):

#![no_std]
#![no_main]
#![feature(abi_avr_interrupt)]

pub mod i2c;
pub mod rtc;
pub mod menu;
pub mod draw;
pub mod oled;
pub mod system;
pub mod buttons;
pub mod chargen;

use buttons::Buttons;
use i2c::I2cDriver;
use oled::Oled;
use rtc::{Rtc, RtcData};

// TODO - abort just hangs on `rjmp .`
use panic_abort as _;

use crate::chargen::{Chargen, SmallFont};

fn draw_date_time(oled: &mut Oled, time: &RtcData) {
	oled.clear_framebuffer();

	draw::time(oled, time, 12, false);
	draw::date(oled, time, 44);

	oled.refresh();
}

fn redraw_clock(rtc: &Rtc, oled: &mut Oled) {
	draw_date_time(oled, &rtc.get_current_time());
}

fn clock_error_screen(oled: &mut Oled) {
	oled.clear_framebuffer();

	SmallFont::draw_string_centered(oled, b"System warning", 16);
	SmallFont::draw_string_centered(oled, b"RTC clock is not present.", 32);
	SmallFont::draw_string_centered(oled, b"Internal clock will be", 40);
	SmallFont::draw_string_centered(oled, b"used instead.", 48);

	oled.refresh();
}

#[avr_device::entry]
fn main() -> ! {
	system::init();

	let rtc = Rtc::init();
	let mut buttons = Buttons::new();
	
	loop {
		rtc.reset_sleep_counter();
		system::enter_high_performance();

		{
			let i2c = I2cDriver::init();
			let mut oled = Oled::init(i2c);

			redraw_clock(&rtc, &mut oled);

			let mut clock_watchdog = 0;

			loop {
				system::enter_low_power();
				system::low_power_delay(10);

				buttons.update();

				if buttons.any_pressed() {
					rtc.reset_sleep_counter();
				}

				if buttons.left().held_down() && buttons.right().held_down() {
					while buttons.left().held_down() { buttons.update(); }
					while buttons.right().held_down() { buttons.update(); }

					system::enter_high_performance();

					menu::setup::run(&mut oled, &mut buttons, &rtc);

					redraw_clock(&rtc, &mut oled);
					rtc.reset_sleep_counter();
					continue
				}

				if buttons.left().held_down() && buttons.middle().held_down() {
					while buttons.left().held_down() { buttons.update(); }
					while buttons.middle().held_down() { buttons.update(); }

					system::enter_high_performance();

					menu::calibration::run(&mut oled, &mut buttons, &rtc);

					redraw_clock(&rtc, &mut oled);
					rtc.reset_sleep_counter();
					continue
				}

				if rtc.should_go_to_sleep() { break }

				if let Some(time) = rtc.updated() {
					system::enter_high_performance();
					draw_date_time(&mut oled, &time);
					clock_watchdog = 0;
				} else {
					clock_watchdog += 1;
				}

				if clock_watchdog > 300 { // 3 seconds, the RTC should have updated
					system::enter_high_performance();
					clock_error_screen(&mut oled);
					system::enter_low_power();
					system::low_power_delay(5000);
					rtc.switch_to_internal_clock();
					clock_watchdog = 0;
				}
			}
		}

		loop {
			buttons.update();

			if buttons.any_pressed() {
				break
			}

			system::enter_low_power();
			system::sleep();
		}
	}
}

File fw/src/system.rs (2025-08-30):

use avr_device::attiny3224::Peripherals;

pub fn peri() -> Peripherals {
	unsafe { core::mem::transmute(()) } // The Peripherals struct literally is 0 bytes in size anyways
}

pub fn delay(ms: usize) {
	for _ in 0..ms {
		avr_device::asm::delay_cycles(5000); // At 5 MHz
	}
}

pub fn low_power_delay(ms: usize) {
	for _ in 0..ms {
		avr_device::asm::delay_cycles(312); // At 312.5 kHz-ish
	}
}

#[inline]
pub fn access_protected_io() {
	peri().CPU.ccp().write(|reg| reg.ccp().ioreg());
}

/// Puts the CPU into high-performance mode (5 MHz).
pub fn enter_high_performance() {
	access_protected_io();
	peri().CLKCTRL.mclkctrlb().write(|reg| reg
		.pdiv()._4x()
		.pen().set_bit());
}

/// Puts the CPU into low-power mode (312.5 kHz).
pub fn enter_low_power() {
	access_protected_io();
	peri().CLKCTRL.mclkctrlb().write(|reg| reg
		.pdiv()._64x()
		.pen().set_bit());
}

/// Initializes the microcontroller.
pub fn init() {
	let peri = peri();

	// Set correct interrupt location

	access_protected_io();
	peri.CPUINT.ctrla().write(|reg| reg.ivsel().set_bit());

	// Set pullups on all pins, otherwise they will oscillate → consume power

	peri.PORTA.dir().write(|reg| reg
		.pa0().clear_bit()
		.pa1().clear_bit()
		.pa2().clear_bit()
		.pa3().clear_bit()
		.pa4().clear_bit()
		.pa5().clear_bit()
		.pa6().clear_bit()
		.pa7().clear_bit());

	peri.PORTB.dir().write(|reg| reg
		.pb0().clear_bit()
		.pb1().clear_bit()
		.pb2().clear_bit()
		.pb3().clear_bit());

	// TODO - is there a less retarded way to do all of this?
	// the assembly for the following looks about as you would expect

	peri.PORTA.pin0ctrl().write(|reg| reg.pullupen().set_bit());
	peri.PORTA.pin1ctrl().write(|reg| reg.pullupen().set_bit());
	peri.PORTA.pin2ctrl().write(|reg| reg.pullupen().set_bit());
	peri.PORTA.pin3ctrl().write(|reg| reg.pullupen().set_bit());
	peri.PORTA.pin4ctrl().write(|reg| reg.pullupen().set_bit());
	peri.PORTA.pin5ctrl().write(|reg| reg.pullupen().set_bit());
	peri.PORTA.pin6ctrl().write(|reg| reg.pullupen().set_bit());
	peri.PORTA.pin7ctrl().write(|reg| reg.pullupen().set_bit());

	peri.PORTB.pin0ctrl().write(|reg| reg.pullupen().set_bit());
	peri.PORTB.pin1ctrl().write(|reg| reg.pullupen().set_bit());
	peri.PORTB.pin2ctrl().write(|reg| reg.pullupen().set_bit());
	peri.PORTB.pin3ctrl().write(|reg| reg.pullupen().set_bit());
}

/// Enters sleep mode. Will wake up with the next interrupt.
pub fn sleep() {
	// Enable standby mode
	
	peri().SLPCTRL.ctrla().write(|reg| reg
		.smode().stdby()
		.sen().set_bit());

	avr_device::asm::sleep();
}

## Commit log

2022-04-29 Removed the pin change interrupt, just caused problems
2022-04-29 Moved the oscillator calibration vars to the user row
2022-04-30 VSCode was complaining 🤷
2022-04-30 More space savings + turbo 🚄
2022-06-25 When a submenu is invoked, wait for both buttons to be released
2022-06-26 Forced the framebuffer to be exactly at addr 0x3800
2022-06-27 Even more flash space savings (thanks in part to inline assembly)
2022-09-30 Added printable 3D models + scad source files
    [buttons.scad, buttons.stl, common.scad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]
2022-09-30 Added KiCad source files
    [buttons.scad, buttons.stl, common.scad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]
2022-09-30 Added BOM
    [tinywatch.csv]
2024-11-09 Turns out I really do not like assembly
2024-11-09 The watch will no longer drain the battery when you accidentally put a heavy box on top of the buttons and leave it like that overnight
2024-11-09 R2 hardware
    [tinywatch.kicad_pcb, tinywatch.kicad_sch]
2024-11-09 Updated BOM
    [tinywatch.csv]
2024-11-09 Updated BOM and README
    [tinywatch.csv, tinywatch.kicad_pcb, tinywatch.kicad_sch]
2025-07-20 Left a trace disconnected, whoops
    [tinywatch.kicad_pcb, tinywatch.kicad_sch]
2025-07-20 Replaced the crystal with a more precise TXCO
    [tinywatch.csv, tinywatch.kicad_pcb, tinywatch.kicad_sch]
2025-07-20 Replaced TXCO footprint with a more solderable variant
    [tinywatch.kicad_pcb, tinywatch.kicad_sch]
2025-08-02 Made the buttons easier to fit
    [buttons.scad, buttons.stl]
2025-08-02 Added labels for "+" and "-"
    [tinywatch.kicad_pcb]
2025-08-03 Reduced power consumption by selecting the external clock instead of crystal
2025-08-03 Added assembly instructions
2025-08-03 Modified OLED support to better suit the current hardware revision
    [oledsupport.scad, oledsupport.stl]
2025-08-03 Added power consumption blerb
2025-08-17 Holding down the button no longer causes excessive CPU load
    [buttons.rs]
2025-08-17 Rtc methods are no longer &self
    [main.rs]
2025-08-17 -570 bytes by making the OLED framebuffer global
2025-08-17 Revert "Rtc methods are no longer &self"
    This reverts commit 002ed1289d6f17a94cd965113bc884d489dd25ae.
    [main.rs]
2025-08-30 Updated to ATtiny3224
    [tinywatch.csv, tinywatch.kicad_pcb, tinywatch.kicad_sch]
